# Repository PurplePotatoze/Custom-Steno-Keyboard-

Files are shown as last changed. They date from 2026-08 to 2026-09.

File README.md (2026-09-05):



#  Steno Keyboard
I'm making my very own Steno Keyboard!! (In a nutshell, its a keyboard that you can type over 200 wpm because of the placement of the keys). 42 Keys, USB-C, with a Raspberry Pi Pico. Thank you Hackclub Stardance for funding this!

BOM:
- 1x Raspberry Pi Pico 2
- 10x M3x5mm Screws
- 10x M3 (3mm) Heatset inserts
- 42x Gateron Low Profile Switches
- 42x Gateron Low Profile Keycaps
- 1x 0.91 OLED (Pin order: GND-VCC-SCL-SDA)
- 1x PCB
- 2x 3D Printed Case
- 1x 1.4 M3 Spacers

Features:
- USB-C
- 42 Reprogrammable Keycaps
- Compatibility with Plover
- 0.91 Oled for status

# CAD



Very simple case, just 10 heat set inserts

# Schematics



42 SW Push in a matrix (12x4) with a 4 pin connector for the oled.

# PCB



Designed in Kicad, gets yours at JLCPCB or PCBway with my Gerber files.

# Firmware



KMK, very simple python based code. Firmware in "Production" file, flash onto Pico. Very modifiable. Also install Plover for the Steno.

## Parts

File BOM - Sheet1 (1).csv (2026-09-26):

Item Name | Quantity | Price (Total USD) | Item Link | Notes
Gateron KS-33 2.0 Low Profile Switches (45 Count) | 1 | $29.60 | Gateron | Yes I check aliexpress and other places, this is the cheapest I found in the quantity i need
1N4148 Diodes | 1 | $1.58 | Aliexpress
M3 Screws and Spacers | 1 | $10.93 | Amazon
M3x3 Heatset inserts | 1 | $6.57 | Amazon
PCB | 1 | $28.55 | JLCPCB
0.91 OLED | 1 | $0 | ME
3D Printed Parts | 1 | $0 | ME
Raspberry Pi Pico 2 | 1 | $11.54 | Amazon | Cheapest becauase I have Prime
Womier Low Profile Keycaps | 1 | $17.19 | Amazon
 |  | $105.96

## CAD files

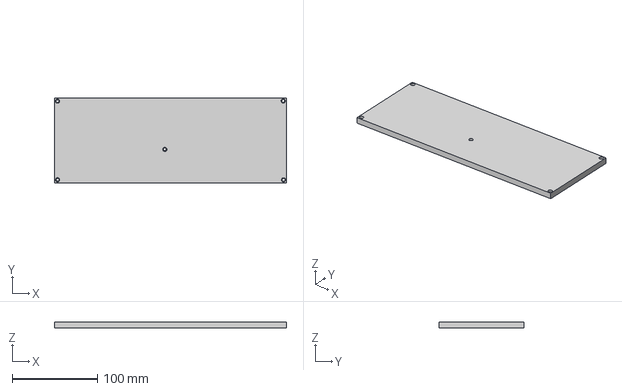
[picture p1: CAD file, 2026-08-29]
CAD/Steno Keyboard Case.step
272.0 x 99.4 x 7.00 mm

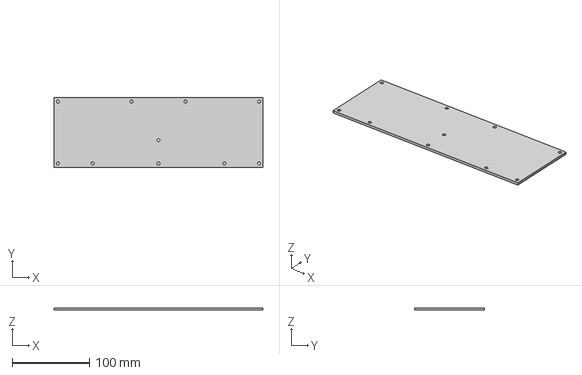
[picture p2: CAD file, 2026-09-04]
Production/Steno Keyboard Case.step
270.0 x 90.0 x 3.00 mm

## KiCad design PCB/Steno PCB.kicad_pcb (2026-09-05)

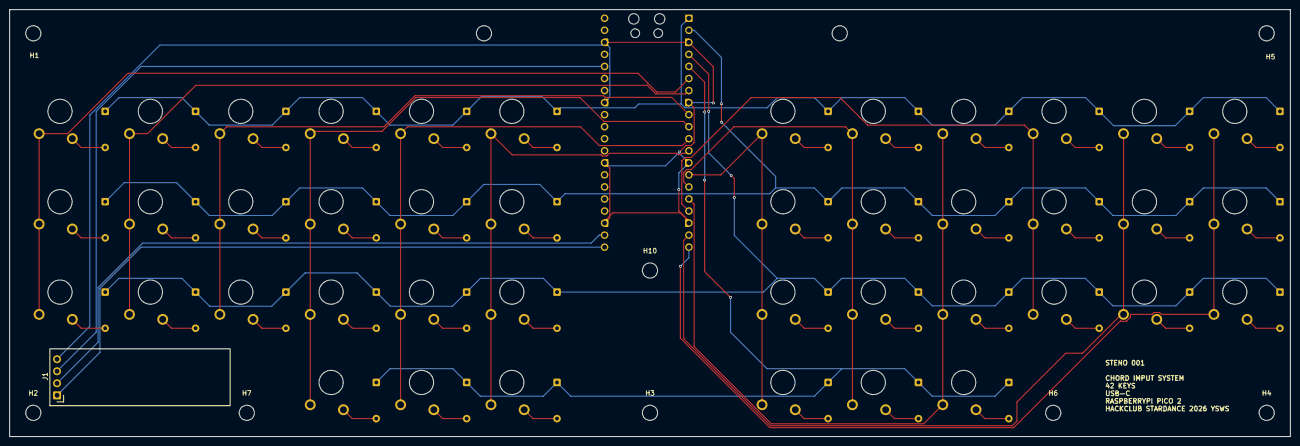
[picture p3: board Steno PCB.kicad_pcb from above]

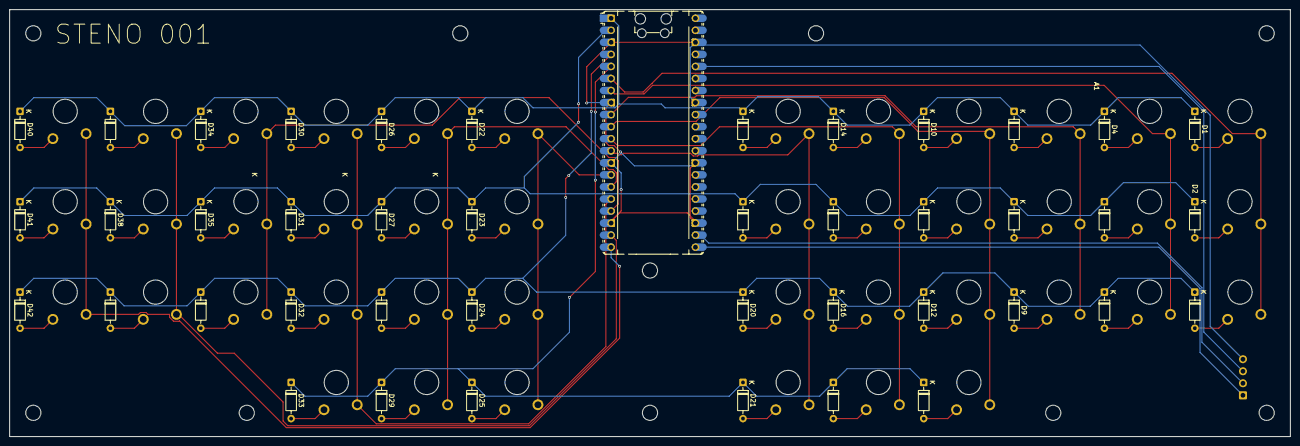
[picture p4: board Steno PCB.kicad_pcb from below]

Board: 2 copper layers, 270.0 x 90.0 mm, 96 parts (43 on the bottom side), 62 nets.

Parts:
A1: RaspberryPi_Pico; RaspberryPi_Pico_Common_Unspecified
D1, D2, D3, D4, D5, D6, D7, D8, D9, D10, D11, D12, D13, D14, D15, D16, D17, D18, D19, D20, D21, D22, D23, D24, D25, D26, D27, D28, D29, D30, D31, D32, D33, D34, D35, D36, D37, D38, D39, D40, D41, D42: 1N4148; D_DO-35_SOD27_P7.62mm_Horizontal
H1, H2, H3, H4, H5, H6, H7, H8, H9, H10: MountingHole; MountingHole_3.2mm_M3
J1: Conn_01x04_Pin; ER_OLEDM0.91_1x-I2C
SW1, SW2, SW3, SW4, SW5, SW6, SW7, SW8, SW9, SW10, SW11, SW12, SW13, SW14, SW15, SW16, SW17, SW18, SW19, SW20, SW21, SW22, SW23, SW24, SW25, SW26, SW27, SW28, SW29, SW30, SW31, SW32, SW33, SW34, SW35, SW36, SW37, SW38, SW39, SW40, SW41, SW42: SW_Push; Gateron-KS33-Solderable-1U

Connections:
+3.3V: A1.36 (3V3), J1.3
/ Column 1: A1.7 (GPIO5), SW4.1, SW5.1, SW6.1
/ Column 10: A1.19 (GPIO14), SW37.1, SW38.1, SW39.1
/Column 0: A1.6 (GPIO4), SW1.1, SW2.1, SW3.1
/Column 2: A1.9 (GPIO6), SW7.1, SW8.1, SW9.1
/Column 3: A1.10 (GPIO7), SW10.1, SW11.1, SW12.1, SW13.1
/Column 4: A1.11 (GPIO8), SW14.1, SW15.1, SW16.1, SW17.1
/Column 5: A1.12 (GPIO9), SW18.1, SW19.1, SW20.1, SW21.1
/Column 6: A1.14 (GPIO10), SW22.1, SW23.1, SW24.1, SW25.1
/Column 7: A1.15 (GPIO11), SW26.1, SW27.1, SW28.1, SW29.1
/Column 8: A1.16 (GPIO12), SW30.1, SW31.1, SW32.1, SW33.1
/Column 9: A1.17 (GPIO13), SW34.1, SW35.1, SW36.1
/Column 11: A1.20 (GPIO15), SW40.1, SW41.1, SW42.1
/Row 0: A1.1 (GPIO0), D1.1 (K), D4.1 (K), D7.1 (K), D10.1 (K), D14.1 (K), D18.1 (K), D22.1 (K), D26.1 (K), D30.1 (K), D34.1 (K), D37.1 (K), D40.1 (K)
/Row 1: A1.2 (GPIO1), D2.1 (K), D5.1 (K), D8.1 (K), D11.1 (K), D15.1 (K), D19.1 (K), D23.1 (K), D27.1 (K), D31.1 (K), D35.1 (K), D38.1 (K), D41.1 (K)
/Row 2: A1.4 (GPIO2), D3.1 (K), D6.1 (K), D9.1 (K), D12.1 (K), D16.1 (K), D20.1 (K), D24.1 (K), D28.1 (K), D32.1 (K), D36.1 (K), D39.1 (K), D42.1 (K)
/Row 3: A1.5 (GPIO3), D13.1 (K), D17.1 (K), D21.1 (K), D25.1 (K), D29.1 (K), D33.1 (K)
/SCL: A1.22 (GPIO17), J1.2
/SDA: A1.21 (GPIO16), J1.1
GND: A1.3 (GND), A1.8 (GND), A1.13 (GND), A1.18 (GND), A1.23 (GND), A1.28 (GND), A1.33 (AGND), A1.38 (GND), J1.4
unnamed: D1.2 (A), SW1.2
unnamed: D2.2 (A), SW2.2
unnamed: D3.2 (A), SW3.2
unnamed: D4.2 (A), SW4.2
unnamed: D5.2 (A), SW5.2
unnamed: D6.2 (A), SW6.2
unnamed: D7.2 (A), SW7.2
unnamed: D8.2 (A), SW8.2
unnamed: D9.2 (A), SW9.2
unnamed: D10.2 (A), SW10.2
unnamed: D11.2 (A), SW11.2
unnamed: D12.2 (A), SW12.2
unnamed: D13.2 (A), SW13.2
unnamed: D14.2 (A), SW14.2
unnamed: D15.2 (A), SW15.2
unnamed: D16.2 (A), SW16.2
unnamed: D17.2 (A), SW17.2
unnamed: D18.2 (A), SW18.2
unnamed: D19.2 (A), SW19.2
unnamed: D20.2 (A), SW20.2
unnamed: D21.2 (A), SW21.2
unnamed: D22.2 (A), SW22.2
unnamed: D23.2 (A), SW23.2
unnamed: D24.2 (A), SW24.2
unnamed: D25.2 (A), SW25.2
unnamed: D26.2 (A), SW26.2
unnamed: D27.2 (A), SW27.2
unnamed: D28.2 (A), SW28.2
unnamed: D29.2 (A), SW29.2
unnamed: D30.2 (A), SW30.2
unnamed: D31.2 (A), SW31.2
unnamed: D32.2 (A), SW32.2
unnamed: D33.2 (A), SW33.2
unnamed: D34.2 (A), SW34.2
unnamed: D35.2 (A), SW35.2
unnamed: D36.2 (A), SW36.2
unnamed: D37.2 (A), SW37.2
unnamed: D38.2 (A), SW38.2
unnamed: D39.2 (A), SW39.2
unnamed: D40.2 (A), SW40.2
unnamed: D41.2 (A), SW41.2
unnamed: D42.2 (A), SW42.2

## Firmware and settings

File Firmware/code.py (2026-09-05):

import board

from kmk.kmk_keyboard import KMKKeyboard
from kmk.keys import KC

class Stenokeyboard(KMKKeyboard):

    def __init__(self):
        super().__init__()

        self.col_pins = (
        board.GP4,
        board.GP5,
        board.GP6,
        board.GP7,
        board.GP8,
        board.GP9,
        board.GP10,
        board.GP11,
        board.GP12,
        board.GP13,
        board.GP14,
        board.GP15,
    )
        self.row_pins = (
        board.GP0,
        board.GP1,
        board.GP2,
        board.GP3,
    )

        self.keymap = [ 
        [  #LAYER 0 - STENO
            KC.NO, KC.S, KC.T, KC.P, KC.H, KC.NO, KC.NO, KC.F, KC.P, KC.L, KC.T, KC.D,

            KC.NO, KC.S, KC.K, KC.W, KC.R, KC.NO, KC.NO, KC.R, KC.B, KC.G, KC.S, KC.Z,

            KC.TG(1), KC.LSHIFT, KC.LCTRL, KC.LALT, KC.LGUI, KC.SPACE, KC.VOL_DOWN, KC.LEFT, KC.UP, KC.DOWN, KC.RIGHT, KC.VOL_UP,

            KC.NO, KC.NO, KC.NO, KC.NO, KC.A, KC.O, KC.E, KC.NO, KC.NO, KC.NO, KC.NO,
            ],

        [   #LAYER 1 - QWERTY
            KC.ESC, KC.Q, KC.W, KC.E, KC.R, KC.T, KC.Y, KC.U, KC.I, KC.O, KC.P, KC.BSPC,

            KC.LCTRL, KC.A, KC.S, KC.D, KC.F, KC.G, KC.H, KC.J, KC.K, KC.L, KC.SCLN, KC.COMMA,

            KC.TG(0), KC.Z, KC.X, KC.C, KC.V, KC.B, KC.N, KC.M, KC.COMMA, KC.DOT, KC.SLSH, KC.ENT,

            KC.NO, KC.NO, KC.NO, KC.LGUI, KC.MO(2), KC.LSHIFT, KC.SPACE, KC.MO(3), KC.LALT, KC.NO, KC.NO, KC.NO,
            ],

        [   #LAYER 2 - NUMBERS
            KC.NO, KC.1, KC.2, KC.3, KC.4, KC.5, KC.6, KC.7, KC.8, KC.9, KC.0, KC.NO,

            KC.TAB, KC.NO, KC.LEFT, KC.DOWN, KC.UP, KC.RIGHT, KC.NO, KC.NO, KC.NO, KC.NO, KC.NO, KC.NO,

            KC.NO, KC.NO, KC.DEL, KC.NO, KC.NO, KC.NO, KC.NO, KC.NO, KC.NO, KC.NO, KC.NO, KC.NO,

            KC.NO, KC.NO, KC.NO, KC.NO, KC.NO, KC.NO, KC.NO, KC.NO, KC.NO, KC.NO, KC.NO, KC.NO,
            ],

        [   #LAYER 3 - SYMBOLS
            KC.NO, KC.EXLM, KC.AT, KC.HASH, KC.DLR, KC.PERC, KC.CARET, KC.AMPERSAND,KC.ASTR, KC.LPRN, KC.RPRN, KC.NO,

            KC.NO, KC.NO, KC.MUTE, KC.VOL_DOWN, KC.VOL_UP, KC.NO, KC.MINUS, KC.EQUAL, KC.LBRACKET, KC.RBRACKET, KC.BSLASH, KC.BTICK,

            KC.NO, KC.NO, KC.NO, KC.NO, KC.NO, KC.NO, KC.UNDS, KC.PLUS, KC.LCBR, KC.RCBR, KC.PIPE, KC.TILD,

            KC.NO, KC.NO, KC.NO, KC.NO, KC.NO, KC.NO, KC.NO, KC.NO, KC.NO, KC.NO, KC.NO, KC.NO,
            ],

        ]

#OLED?
        self.enable_oleds = True
        self.oled_sda = [board.GP16]
        self.oled_scl = [board.GP17]
        self.oled_width = [128]
        self.oled_height = [32]
        self.oled_count = 1
        self.make_oleds()

keyboard = Stenokeyboard()
keyboard.go()

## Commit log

2026-08-29 Rename Steno Keyboard Case.step to CAD/Steno Keyboard Case.step
    [Steno Keyboard Case.step]
2026-09-04 Improved case to fit PCB, added heatset inserts
    [Steno Keyboard Case.step]
2026-09-04 Add Steno Keyboard CaseV2 file
    [Steno Keyboard CaseV2.step]
2026-09-04 Rename Steno Keyboard CaseV2.step to CAD/Steno Keyboard CaseV2.step
    [Steno Keyboard CaseV2.step]
2026-09-05 Revise README with project details and specifications
    Updated README to include detailed specifications, BOM, features, CAD, schematics, PCB design, and firmware information for the Steno Keyboard project.
2026-09-05 Rename Steno Keyboard Case.step to Production/Steno Keyboard Case.step
    [Steno Keyboard Case.step]
2026-09-05 Rename Steno PCB.kicad_pcb to PCB/Steno PCB.kicad_pcb
    [Steno PCB.kicad_pcb]
2026-09-05 Rename Steno PCB.kicad_pro to PCB/Steno PCB.kicad_pro
2026-09-05 Rename Steno PCB Production.zip to Production/Steno PCB Production.zip
2026-09-05 Update bom.cvs with new component details
    Added various components with quantities and prices for a project.
2026-09-05 Update BOM with subtotal and estimated total cost
    Added subtotal and estimated total cost for BOM.
2026-09-25 Update and rename bom.csv to BOM.csv
    [BOM.csv, bom.csv]
